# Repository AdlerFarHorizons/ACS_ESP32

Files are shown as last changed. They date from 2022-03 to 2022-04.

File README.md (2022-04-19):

# ACS_ESP32
### Current State of ACS Development (April 2022)

The Altitude Control System has been updated to work with the ESP32 Microcontroller which has enabled wireless file sharing via WiFi. The exact module is the **DOIT ESP32 DEVKIT V1**. 

**Firmware**

The [ACS_ESP32 Code](https://github.com/AdlerFarHorizons/ACS_ESP32) has been organized for clarity, usage, and further development. The code now lives publicly within the [Adler Far Horizons GitHub](https://github.com/AdlerFarHorizons). Additionally, the code and the libraries are packaged by the [PlatformIO](https://platformio.org/platformio-ide) package, which runs within [VS Code](https://code.visualstudio.com/), and should be used to maintain and update the code. Cloning the repository from within GitHub will ensure PlatformIO compiles the code properly. 



The following are updates to the code:



- Code has been organized into separate header files (_name_.h) so as to keep all related code for specific peripherals in separate files. This allows the programmer to quickly find specific functions.
- Wireless file retrieval has been added. The microcontroller will broadcast a hotspot with SSID: “ACS SD-CARD”. The SD Card content can be displayed by entering the IP-ADDRESS: “192.168.4.1” into a web browser after establishing wifi connection. 

To access wifi settings, 

1. Turn on the ACS by using the Toggle ON/OFF switch or by plugging using a USB cable.

2. Using your computer (or mobile device), look for the “ACS SD-Card” Hotspot under the WIFI settings. You do not need a password to access the hotspot.

3. Identify the 3-position switch on the ACS Faceplate. Place this switch to the Closed Position (or the center position), and Press the Button as indicated on the Display. You should now see the IP Address displayed, which should be “192.168.4.1”.

   1. Sometimes the connection is poor, and you may need to bring the ACS closer to you, or you may need to reestablish the WIFI connection by turning off/on your wireless antenna on your computer/mobile device.

4. If your connection is established, you should now see a window as shown below: 

Within this window you may browse through the content within the SD Card by selecting Directory. If you wish to download a file, you can copy/paste the full name of the file and paste it into the Downloads prompt window. 

The use of WIFI is to be able to download the param.txt file, edit it and upload it back into the ACS SD Card. Additionally, one can download the datalog.csv, which contains all the flight ACS data. Ideally, one should not have to remove the SD Card from the board. 

__Note: I’ve noticed that deleting a file via WIFI sends it to the .Trash Folder. It doesn’t fully delete the file. So when the script runs and looks for a file within the list of files, if the file exists within the .Trash folder, then the code will send a True that the file exists. The code either needs a exception to not search within .Trash or a “Permanently Delete” function that deletes the content within .Trash.__

### Design Files, Notes, and Code

[GitHub - ACS_ESP32](https://github.com/AdlerFarHorizons/ACS_ESP32)

[Google Drive: System Redesign Concept 2021/22](https://drive.google.com/drive/folders/1W37AFGbH8UgUThIRDDYVn1NRzvqxMLDn)

- [PCB Design Files](https://drive.google.com/drive/folders/1NPGxpG3kCgMrHuZ5ZHsxEYcvnIpvRIrO?usp=sharing)
- [PCB Schematic PDF](https://drive.google.com/file/d/19PMDI1tQQiT3bByivIbot_-rFZreG9Ll/view?usp=sharing)

[Purchase Materials****](https://docs.google.com/spreadsheets/d/1xs60UxvHJ-fiQykCOm7pP0R7RBD7VAjFjShzD04MD6w/edit#gid=0)

**Compiling using Arduino**

To compile and upload the script file using Arduino, you must install the ESP32 Arduino Boards using instructions found here.

**Instructions**: [Installing ESP32 in Arduino IDE](https://randomnerdtutorials.com/installing-the-esp32-board-in-arduino-ide-windows-instructions/) 

Upon Install, select the **DOIT ESP32 DEVKIT V1 **Board from the drop down menu within **Tools/Board/ESP32 Arduino/. **The this dropdown menu is shown below:



**Printed Circuit Board (PCB)**

The PCB for the ACS has had several modifications. Primarily, the Teensy 3.6 Microcontroller has been exchanged for the WIFI capable microcontroller [**ESP-WROOM-32 ESP-32S Development Board**](https://www.amazon.com/dp/B08D5ZD528?psc=1&ref=ppx_yo2ov_dt_b_product_details)**. **This microcontroller does not include an SD Card Reader, which is why an [SD Card Reader Breakout Board](https://www.sparkfun.com/products/13743) has been added to the new design. 

In addition to the microcontroller modifications, the PCB now utilizes a few surface-mounted devices. 

- **Power**: The previous design used the [LM7805 Voltage Regulator](https://www.sparkfun.com/datasheets/Components/LM7805.pdf) which dropped the 7.2V to 5V using a conventional heat dissipation voltage regulator. This approach worked, but consumed much higher current draw. Therefore, the DC-DC voltage regulator was exchanged for a low-dropout voltage regulator. The selected voltage regulator is now the [MC33269](https://www.onsemi.com/pdf/datasheet/mc33269-d.pdf). 
- **Logic Level Shifter: The original [4-channel I2C-safe Bi-directional Logic Level Converter - BSS138](https://www.adafruit.com/product/757) has been stripped down to only use 1 of the [BSS138](https://www.onsemi.com/pdf/datasheet/bss138-d.pdf) configured to convert signals from low voltage 3V3 to 5.0 Volts.**
- **Actuator**: The current actuator is the L12-50-210-6-R, which runs a servo motor to extend the actuator. However, this actuator does not provide feedback positional data, therefore the recommendation is to upgrade the actuator to the [**L12-50-210-6-I**](https://s3.amazonaws.com/actuonix/Actuonix+L12+Datasheet.pdf)**. **The L12-I version contains an integrated microcontroller which allows the user to obtain positional feedback data. 

**Connection Diagram**

**AA Battery Set for Actuator + Primary Board**

The current AA battery set used in the ACS is the [ Xeno XL-060F AA 2400mAh 3.6V Lithium Thionyl Chloride (LiSOCI2)](https://www.batteryjunction.com/xl-060f-xeno-aa.html) \[[datasheet](https://files.batteryjunction.com/frontend/files/xeno/datasheet/Xeno-XL-060F-Datasheet.pdf)], which is placed in Series to increase the voltage to 7.2. The ACS uses four (4) AA Batteries - 2 sets in Series, and those two sets are merged in parallel to increase the capacity (mAh).

**External Temperature Battery Board**

This board has been prepared to connect to the primary board, but is placed separately from it in order to be close enough to the heating elements for it to monitor temperatures and hold the two 9V batteries to power the heating element.

- **Temperature:** The temperature is monitored using a [DS18B20 Digital Thermometer](https://datasheets.maximintegrated.com/en/ds/DS18B20.pdf).
- **Batteries:** The 9V batteries are held in place by both the structure of the compartment it will reside in and power the heating through two [5331TR (Leaf-Spring Battery Contacts)](https://www.digikey.com/en/products/detail/keystone-electronics/5331TR/8347168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) each. These battery contacts serve a dual purpose as the screws that will go through them are the same ones being used to mount the board securely.
- **Connection: The board is connected to the primary one using a 5 Pin [Screw Terminal Block](https://www.pololu.com/product/2493) affixed to the bottom of the board which will allow wires to be led through a hole beneath it on the way to the main board.**

****

### NEXT TASKS

**Actuator**

- After providing 6.5V to the L-12-I actuator via the DC-Power Supply, **ensure the actuator responds correctly to the ACS_ESP32 Code**. If it does not respond correctly, change the RC_INPUT_SIG Pin to another pin on the ESP32. I’ve identified that some of the pins on the ESP32 seem to short out the microcontroller and/or do not behave as intended. On the code, navigate to actuator.h and find line “**int actuator_pin = 17;”.** Test out a different GPIO pio, upload code, and test for actuator response. 

  - If the actuator ‘jerks’ back and forth when attempting to reach a certain position, the datasheet recommends to “place a 1–4Ω resistor in series with the actuator’s red V+ lead wire”.

- **Actuator Feedback** via the POS_FEEDBACK_SIG pin, which has been connected to GPIO13, must be checked for incoming data. After declaring the POS_FEEDBACK_PIN as an int, use pinMode(POS_FEEDBACK_PIN, INPUT); to initialize the pin on the microcontroller, one should be able to read the voltage using the analogRead() function. One should expect a voltage reading from 0-255, which then can be mapped using map() to correspond to a percentage. 

- Actuator Pins CURR_INPUT_SIG and VOLT_INPUT_SIG have purposefully been disconnected from the microcontroller. These features for controlling the actuator are unnecessary as the actuator will be controlled via the RC_INPUT_SIG.

**The Heating Element**

- The Heating Element needs to be tested the new downsize of voltage output. Originally the heating element uses 3 batteries in series of 9V totalling 27V. Now, the downsize should yield 18V. This downsize has been considered given the usage of an aluminum pipe for heat distribution. 
- Code: Create Algorithm to measure heat transfer between the heating element and the internal electronics, by measuring the temperature outside the heating element (battery board) and the internal Pressure Sensor thermometer. Using these temperatures, create a function that activates the heating element below a specific temperature, and conversely deactivates the heating element when temperatures reach a specific maximum. 
- Heating Element Transistor 2N2222 schematic needs to be tested prior to finalizing the schematic design of the primary board. 



Above: Circuit concept idea for the resistor being the heating element connected to one end of the transistor 2N2222.



Above: Schematic capture of the heating element connector. Here the heating element is connected to one side of the NPN transistor. The Base is connected to the microController, and the Collector is connected to the negative end of the 9V battery set, which is connected in series. 

**Code**

Within the void setup() function, ensure that when the sd_setup() does not create a new file each time the boot process occurs. The ACS should conserve and append the currently existing logfile if it exists. If the file does not exist, the code is instructed to write the parameters below:

else
{ unsigned long size = logFile.size();
  Serial.print("Filesize: "); Serial.println(size);
  delay(5000);
  if (size < 500){
    display.clearDisplay();
    display.println("Creating new File");
    display.display();
    delay(5000);

    String log = 
                "Far Horizons | Adler Planetarium" + String("\n") + 
                "Flight Number: " + "," +            String(flightNum) + "\n" + 
                "Firmware: " + "," +                  String(the_sketchname) + "\n" + 
                "Compiled on: " +  "," +               String(__DATE__) +  " at " +  String(__TIME__) + "\n" +
                "Venting Altitude (m): " + "," +      String(VENT_ALT) + "\n" + 
                "Float Time (min): " + "," +          String(FLOAT_TIME) + "\n" + 
                "Max Float Altitude (m): " + "," +   String(MAXFLOATALT) + "\n" + 
                "Release Position %: " + "," +        String(RELEASE_POS) + "\n" + 
                "Venting Position %: " + "," +        String(OPEN_POS) + "," + 
                "Closed Position" + "," + String(CLOSED_POS) + "\n";

Currently this section of the code does not work as intended. Instead, the code creates a new file and does not append the parameters found above.

**ACS Primary PCB**

- Label Pins on Connectors using layer tNames and bNames.
- Ensure Connector are placed in the correct location to help diminish excess wire routing and unnecessary wire-curvatures.
- Rework routes after device placement and use ratsnest to create the correct ground plane

**Currently Wired Diagram on Breadboard: **

  

**Full Schematic Diagram with External Temp Board**

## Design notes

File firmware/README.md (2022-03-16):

# ACS_ESP32

This code runs on PlatformIO using VSCode.
Use Microcontroller: esp32doit-devkit-v1

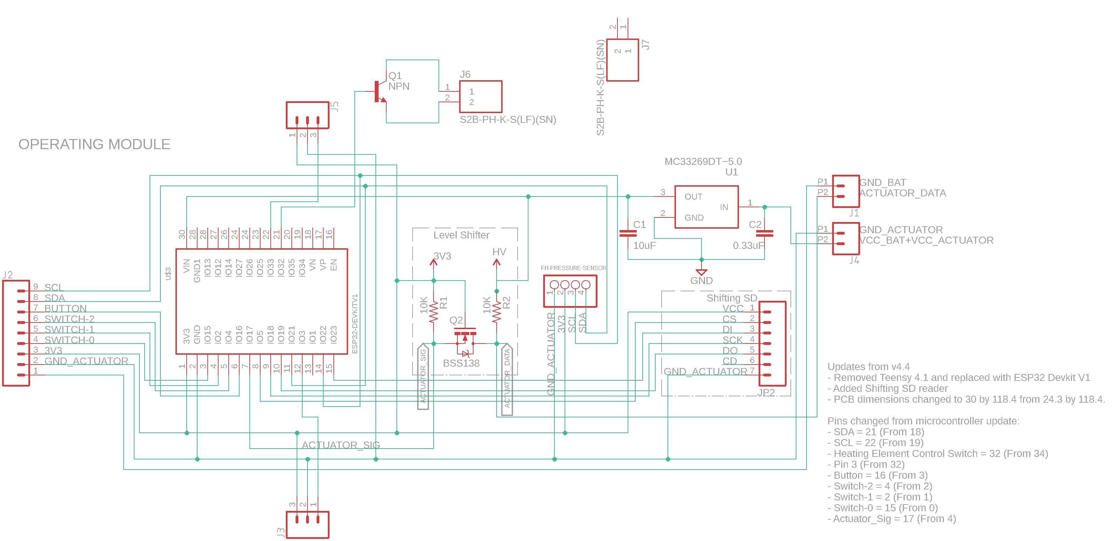
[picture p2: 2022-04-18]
pcb/ACS_5.X_REDESIGN/5.1.1/ACS_Schematic.png

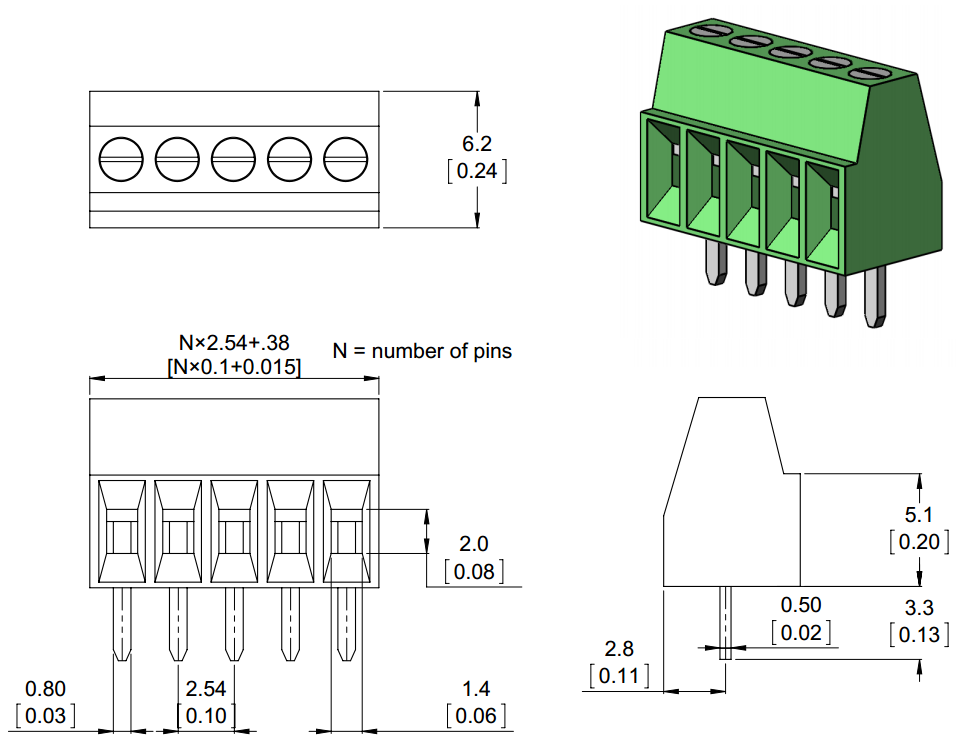
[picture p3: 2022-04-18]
pcb/datasheet/block_connectors.png

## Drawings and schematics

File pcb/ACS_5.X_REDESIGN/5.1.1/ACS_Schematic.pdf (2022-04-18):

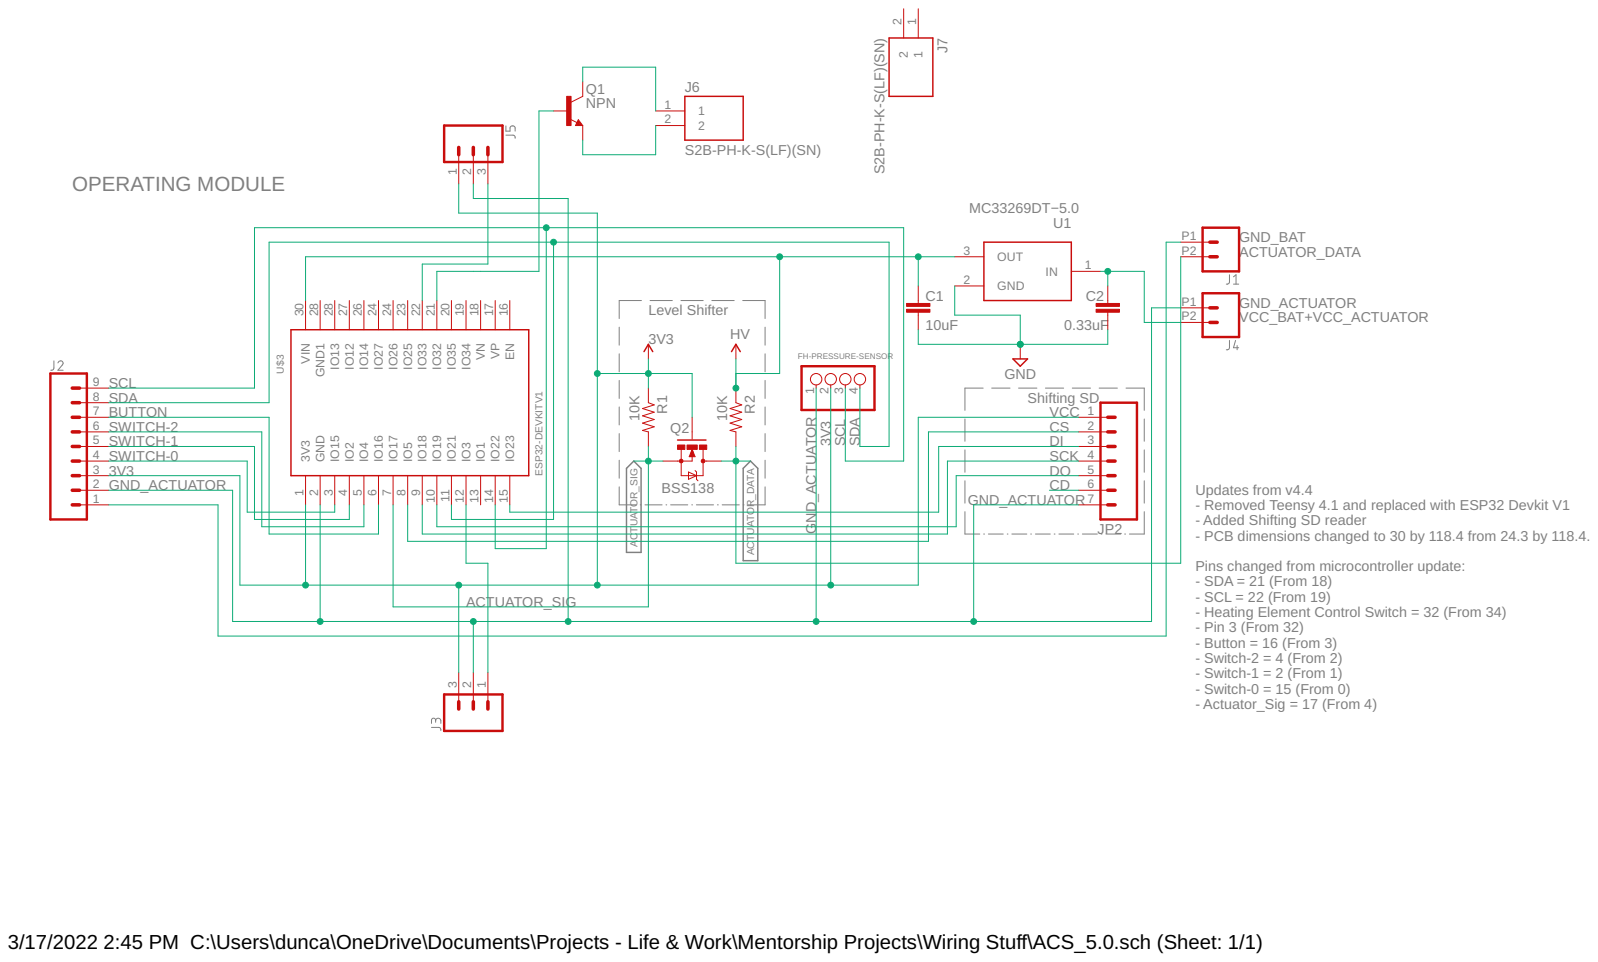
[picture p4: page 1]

CS 2
DI 3
SCK 4
DO 5

Updates from v4.4
- Removed Teensy 4.1 and replaced with ESP32 Devkit V1
- Added Shifting SD reader
- PCB dimensions changed to 30 by 118.4 from 24.3 by 118.4. Pins changed from microcontroller update: - SDA = 21 (From 18)

- SCL = 22 (From 19)
- Heating Element Control Switch = 32 (From 34)
- Pin 3 (From 32)
- Button = 16 (From 3)
- Switch-2 = 4 (From 2)
- Switch-1 = 2 (From 1)
- Switch-0 = 15 (From 0)
- Actuator_Sig = 17 (From 4)

3/17/2022 2:45 PM C:\Users\dunca\OneDrive\Documents\Projects - Life & Work\Mentorship Projects\Wiring Stuff\ACS_5.0.sch (Sheet: 1/1)

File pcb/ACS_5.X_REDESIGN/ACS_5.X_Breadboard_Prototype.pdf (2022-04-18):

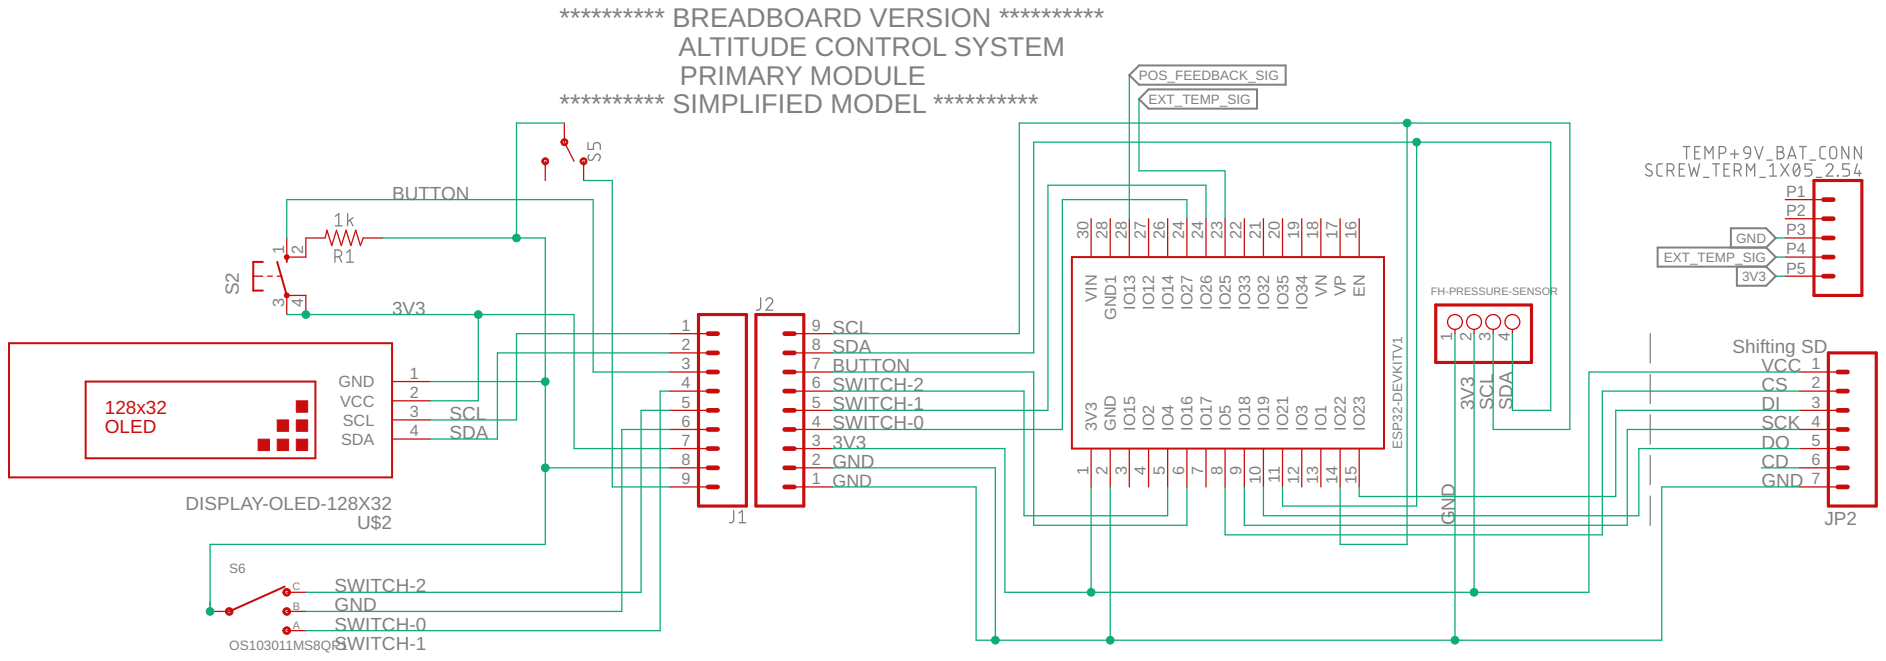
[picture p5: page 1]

********** BREADBOARD VERSION ********** ALTITUDE CONTROL SYSTEM

SCK 4
DO 5
6 CD

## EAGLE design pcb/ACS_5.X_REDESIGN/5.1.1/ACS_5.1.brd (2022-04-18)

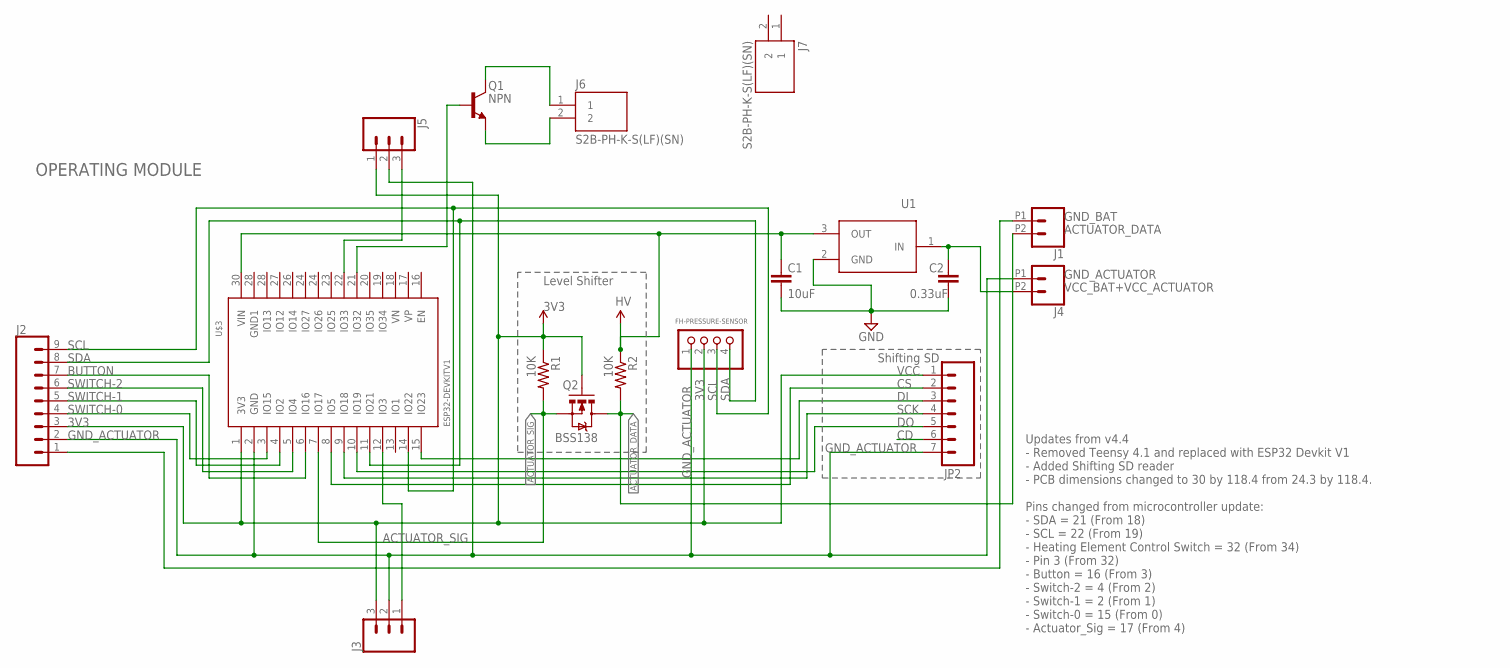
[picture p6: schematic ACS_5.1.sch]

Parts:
C1: 10uF; CAPC1608X85
C2: 0.33uF; CAPC1608X85
FH-PRESSURE-SENSOR: PINHD-1X4; 1X04
J1, J4: CONN_022.54MM_SCREWTERM; 1X02_2.54_SCREWTERM
J2: CONN_09; 1X09
J3, J5: CONN_03; 1X03
J6, J7: S2B-PH-K-S(LF)(SN); JST_S2B-PH-K-S(LF)(SN)
JP2: M07; 1X07
Q1: NPN; SOT95P237X112-3N
Q2: BSS138; SOT23-3
R1, R2: 10K; 0603-RES
U1: MC78M05BDTRKG
U$3: ESP32DEVKITV1; ESP32-DEVKITV1

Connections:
3V3: FH-PRESSURE-SENSOR.2, J2.3, J3.3, J5.1, JP2.1, Q2.1 (G), R1.1, U$3.1 (3V3)
ACTUATOR_DATA: J1.P2 (2), Q2.3 (D), R2.2
ACTUATOR_SIG: Q2.2 (S), R1.2, U$3.7 (IO17)
BUTTON: J2.7, U$3.6 (IO16)
GND: C1.2, C2.2, U1.2 (GND)
GND_ACTUATOR: FH-PRESSURE-SENSOR.1, J2.2, J3.2, J4.P1 (1), J5.2, JP2.7, U$3.2 (GND)
GND_BAT: J1.P1 (1), J2.1
HV: C1.1, R2.1, U1.3 (OUT), U$3.30 (VIN)
unnamed: J5.3, U$3.22 (IO33)
unnamed: J6.1, Q1.3 (C)
unnamed: J6.2, Q1.1 (E)
unnamed: Q1.2 (B), U$3.21 (IO32)
unnamed: J3.1, U$3.12 (IO3)
unnamed: JP2.3, U$3.15 (IO23)
unnamed: JP2.2, U$3.8 (IO5)
unnamed: JP2.4, U$3.9 (IO18)
unnamed: JP2.5, U$3.10 (IO19)
SCL: FH-PRESSURE-SENSOR.3, J2.9, U$3.14 (IO22)
SDA: FH-PRESSURE-SENSOR.4, J2.8, U$3.11 (IO21)
SWITCH-0: J2.4, U$3.3 (IO15)
SWITCH-1: J2.5, U$3.4 (IO2)
SWITCH-2: J2.6, U$3.5 (IO4)
VCC_BAT+VCC_ACTUATOR: C2.1, J4.P2 (2), U1.1 (IN)

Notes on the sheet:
OPERATING MODULE
Level Shifter
Updates from v4.4 - Removed Teensy 4.1 and replaced with ESP32 Devkit V1 - Added Shifting SD reader - PCB dimensions changed to 30 by 118.4 from 24.3 by 118.4. Pins changed from microcontroller update: - SDA = 21 (From 18) - SCL = 22 (From 19) - Heating Element Control Switch = 32 (From 34) - Pin 3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
SCK
VCC
Shifting SD

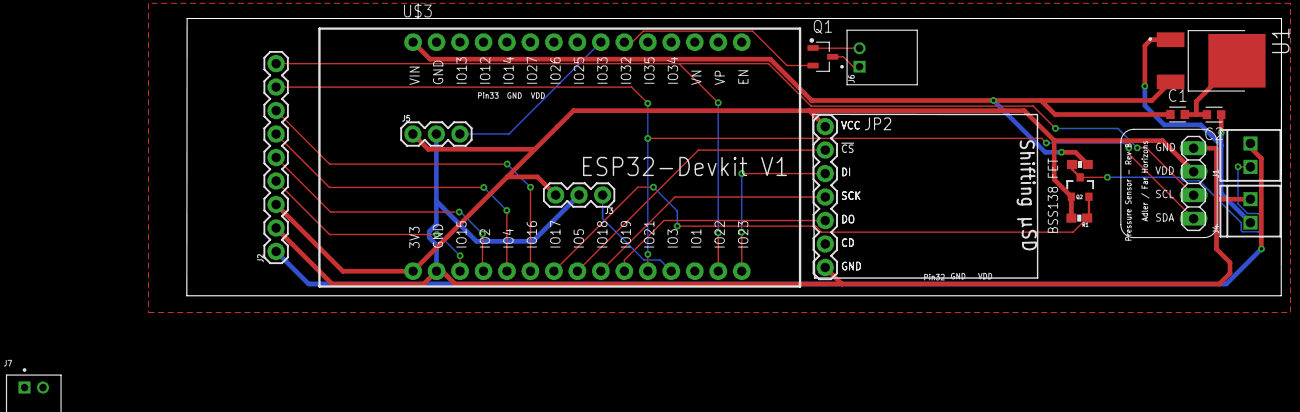
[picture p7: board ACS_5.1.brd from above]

Board: 2 copper layers, 118.4 x 30.0 mm, 17 parts (0 on the bottom side), 23 nets.

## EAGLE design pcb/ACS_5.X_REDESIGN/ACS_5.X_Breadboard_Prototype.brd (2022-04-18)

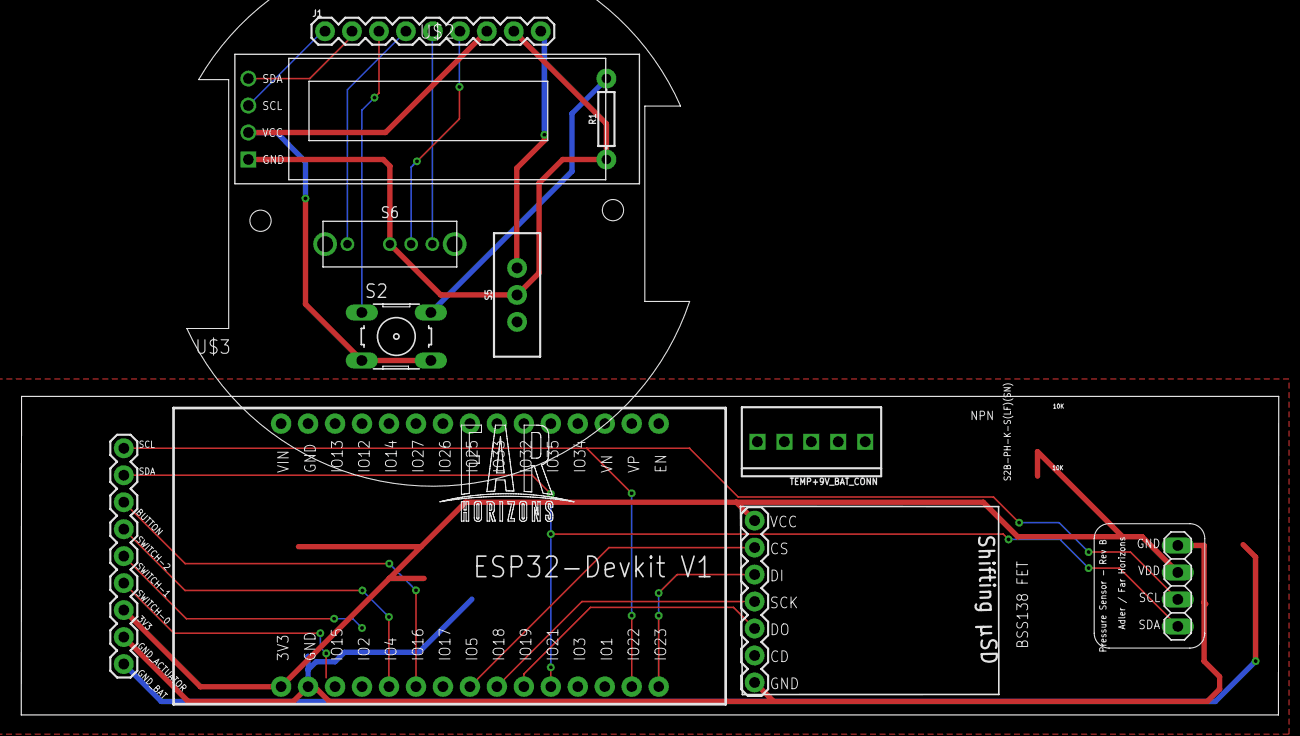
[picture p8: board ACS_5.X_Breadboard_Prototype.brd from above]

Board: 2 copper layers, 118.4 x 30.0 mm, 11 parts (0 on the bottom side), 15 nets.

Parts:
FH-PRESSURE-SENSOR: 1X04
J1, J2: 1X09
JP2: 1X07
R1: 1k; AXIAL-0.3
S2: B3F-10XX
S5: SWITCH_SPDT_PTH_11.6X4.0MM
S6: OS103011MS8QP1; OS102011MS8QP1
TEMP+9V_BAT_CONN: SCREW_TERM_1X05_2.54; 1X05_2.54_SCREWTERM
U$2: DISPLAY-OLED-128X32
U$3: ESP32DEVKITV1; ESP32-DEVKITV1

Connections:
3V3: FH-PRESSURE-SENSOR.2, J1.7, J2.3, JP2.1, S2.3, S2.4, TEMP+9V_BAT_CONN.P5, U$2.2, U$3.1
BUTTON: J1.3, J2.7, S2.1, U$3.6
EXT_TEMP_SIG: TEMP+9V_BAT_CONN.P4, U$3.23
GND: FH-PRESSURE-SENSOR.1, J1.8, J2.1, J2.2, JP2.7, R1.P$1, S5.2, S6.2, TEMP+9V_BAT_CONN.P3, U$2.1, U$3.2
unnamed: R1.P$2, S2.2
unnamed: J1.9, S5.1
unnamed: JP2.3, U$3.15
unnamed: JP2.2, U$3.8
unnamed: JP2.4, U$3.9
unnamed: JP2.5, U$3.10
SCL: FH-PRESSURE-SENSOR.3, J1.1, J2.9, U$2.3, U$3.14
SDA: FH-PRESSURE-SENSOR.4, J1.2, J2.8, U$2.4, U$3.11
SWITCH-0: J1.6, J2.4, S6.3, U$3.24
SWITCH-1: J1.5, J2.5, S6.4, U$3.24
SWITCH-2: J1.4, J2.6, S6.1, U$3.5

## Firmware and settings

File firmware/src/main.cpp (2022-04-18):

/*
Altitudde Control System 
Adler Planetarium | Far Horizons

By: Jesus Garcia
ACS WIFI on ESP32

4/11/2022
- Password removed.
- Updated WebPage Style

 3/26/2022
WIFI is enabled at startup and can be assessed via Switch State: Closed and Button Press
SSID has been added: ACS SD-CARD PSWORD: xxxxxxx
?? Do we need a Password? 
When Switch State is in Closed Possition, button may be pressed to enter WIFI.

External TEMP has been added and called within setup and loop.
TODO: Add Temperature Control for Heating Element

So far, this code compiles with Pressure code, Actuator, SD + Wifi, reads/writes parameter file. 
     reads all variables from sensors, calculates dA/dt, and writes into var = dataString 
     and appends to SD Card

*/

#include <Arduino.h>
#include <math.h>             // math .. Pressure Sensor needs this
#include <String.h>
#include <Wire.h>             //I2C library fort OLED and Pressure Sensor
#include <SPI.h>              //SPI library for SD card
#include <SD.h>               //SD    ********MUST BE VERSION 1.2.2 TO WORK WITH TEENSY********
#include <EEPROM.h>


// Local Files
#include "actuator.h"
#include "Globals+switch.h"
#include "pressure.h"
#include "sd+wifi.h"
#include "oled.h"
#include "param.h"
#include "SoftwareFunctions.h"
#include "temp.h"

String the_sketchname, version;
String header;


// displays at startup the Sketch running in the Arduino
void display_Running_Sketch (void){
  String the_path = __FILE__;
  int slash_loc = the_path.lastIndexOf('/');
  String the_cpp_name = the_path.substring(slash_loc+1);
  int dot_loc = the_cpp_name.lastIndexOf('.');
  the_sketchname = the_cpp_name.substring(0, dot_loc);
  version = the_sketchname.substring(0,4);
  
  Serial.println("\nArduino is running Sketch: ");
  Serial.println(the_sketchname);
  Serial.println("Compiled on: ");
  Serial.println(__DATE__);
  Serial.println(" at ");
  Serial.println(__TIME__);
  Serial.println("\n");
}

void setup() {
  Serial.begin(115200);

  display_Running_Sketch();

  // Setup Pins
  pinMode(switch0, INPUT_PULLUP);
  pinMode(switch1, INPUT_PULLUP);
  pinMode(switch2, INPUT_PULLUP);
  
  // initialize Pin for the button
  pinMode(buttonPin, INPUT_PULLUP);
  buttonPressed=FALSE;

    // Attach Actuator
  actuator.attach(actuator_pin);

    // Setup Pressure Sensor
  pressure_setup();
  
  // EXT Temp Sensor Setup
  temp_setup();

  // Setup Display
  oled_setup();

  // Setup SD
  sd_setup();

  //Access Point Initialized
  Start_Wifi();

  // Read Parameters File and/or creates param.txt file (with default values) if not present
  readparam(SD);

  // get the current altitude for deciding how to initialize
  currentAltitude=getMedianPressure(&currentTemp);
  
  
  // if the switch is indicating that we are in flight mode (that is we were in the middle of a 
  // mission when the power cycled) them attempt to pick up from where we left
    FS fs(SD);
    File logFile;

  if (switchPos(currentAltitude)==FLIGHT) {
    char lineBuf[250];          //For log file


    // open logfile -> dataFile
    if ((logFile = fs.open(dataFile, FILE_READ))) { 
        Serial.println("Reading LAST LINES on File .......");
      // read the last line of the log file to get programState, the timeOffset, 
      // actuator extension, and the start of floating
      while (logFile.available()) {
          logFile.readBytesUntil('\n',lineBuf,150);    
      }

      Serial.println("\n***************************** \n");
      Serial.print("Last Line in Buffer: ");
      Serial.println(lineBuf);
      // we should have the last line now
      sscanf(lineBuf, "%ld %*d %d %f %ld",&timeOffset, &programState, &currentActuatorExtension, &floatStartTime);
      Serial.print("Time Offset: "); Serial.println(timeOffset);
      Serial.print("Program State: "); Serial.println(programState);
      Serial.print("Current Actuator Extension: "); Serial.println(currentActuatorExtension);
      Serial.print("Float Start TIme: "); Serial.println(floatStartTime);
      Serial.println("\n***************************** \n");
    
      SetStrokePerc(currentActuatorExtension);
    }
  }
  
////////////////////////////

//   TODO   FIX this section... Check if file exists and report if file exits, otherwise create file and append log parameters.

  // open logfile
  if (!(logFile = fs.open(dataFile, FILE_APPEND))) { 
    Serial.println("Failed to open logfile.");
    display.clearDisplay();
    display.setTextSize(2); 
    display.setTextColor(WHITE);
    display.setCursor(18, 0);
    display.println("LOGFILE");
    display.setCursor(18, 16);
    display.println("FAILED");
    display.display();
    delay(5000);
    //return;
    }
  else
    { unsigned long size = logFile.size();
      Serial.print("Filesize: "); Serial.println(size);
      delay(5000);
      if (size < 500){
        display.clearDisplay();
        display.println("Creating new File");
        display.display();
        delay(5000);

        String log = 
                    "Far Horizons | Adler Planetarium" + String("\n") + 
                    "Flight Number: " + "," +            String(flightNum) + "\n" + 
                    "Firmware: " + "," +                  String(the_sketchname) + "\n" + 
                    "Compiled on: " +  "," +               String(__DATE__) +  " at " +  String(__TIME__) + "\n" +
                    "Venting Altitude (m): " + "," +      String(VENT_ALT) + "\n" + 
                    "Float Time (min): " + "," +          String(FLOAT_TIME) + "\n" + 
                    "Max Float Altitude (m): " + "," +   String(MAXFLOATALT) + "\n" + 
                    "Release Position %: " + "," +        String(RELEASE_POS) + "\n" + 
                    "Venting Position %: " + "," +        String(OPEN_POS) + "," + 
                    "Closed Position" + "," + String(CLOSED_POS) + "\n";
        // writeFile(SD, dataFile, log);
        appendFile(SD, dataFile, log);
        header = "Current Time,Switch State,Program State,Actuator Extension,Float Start Time,Pressure,Altitude,dAdt,Temp,ExtTemp\n";
        appendFile(SD, dataFile, header);
        
        Serial.println("LOG FILE CREATED with DEFAULT PARAMETERS");
        delay(500);
      }
    }

////////////////////////////
  String parameterText = "Venting Alt: " + String(VENT_ALT) + " m" + "\n" + 
                         "Float Time: "  + String(FLOAT_TIME) + " min" + "\n" + 
                         "MaxFloatAlt: " + String(MAXFLOATALT) + " m" + "\n" + 
                         "Open/Closed_pos: " + String(OPEN_POS) + "/" + String(CLOSED_POS) + " %";
                         
  OLEDScrollText(parameterText);    // prints parameters on OLED with scrolling text
  delay(2000);
  
  lastLogTime=-9999;
  Serial.println(header);
}

void loop(){
  int switchState;
  long int currentTime;
  float currentPressure,currentTemp,currentAltitude,currentDAdt;
  // get time
  currentTime=millis()+timeOffset;
  
  // get EXT Temp
  get_temp();

  // get pressure sensor values
  currentPressure= getMedianPressure(&currentTemp);

  // derive altitude and derivative  
  currentAltitude=altitudeFromPressure(currentPressure);
  currentDAdt=dAdt_fiT_2(currentAltitude,currentTime);

  // process switch and button
  switchState = switchPos(currentAltitude);
  if (digitalRead(buttonPin) == HIGH) buttonPressed=TRUE; 
  
  // Prepares all variable data for write to SD.
  dataString = 
    String(currentTime) + "," + 
    String(switchState) + "," + 
    String(programState) + "," + 
    String(currentActuatorExtension) + "," + 
    String(floatStartTime) + "," + 
    String(currentPressure) + "," + 
    String(currentAltitude) + "," + 
    String(currentDAdt) + "," + 
    String(currentTemp) + "," + 
    String(ext_temp) + "\n"; // Replace with external Temp sensor Dallas...
    lastLogTime=currentTime;
  
  // Append to SD.
  appendFile(SD, dataFile, dataString);     //Append the contents of the dataString to the end of the file on a new line.

  display.clearDisplay();
  display.setCursor(0,20);
  logFileStatus();        // CHECK STATUS OF SD CARD

  switch (switchState) {
    case(RELEASE):
        display.setCursor(0,0);
        display.println("Press to RELEASE");
        display.setCursor(0,16);
        display.println("Actuator will retreat");

        if (buttonPressed) {
          display.clearDisplay();
          display.setCursor(16,16);
          display.println("Button pressed");
          delay(100);
          buttonPressed=FALSE;
          SetStrokePerc(RELEASE_POS);
        }
        programState=GROUND;
        logFileStatus();        // CHECK STATUS OF SD CARD
        display.display();
        break;
    case(CLOSED):
        display.setCursor(0,0);
        display.println("CLOSED POSITION");
        display.print("Pres: "); display.println(currentPressure);
        display.println("Closing Nozzle...");
        display.println("PRESS BUTTON FOR WIFI");
        logFileStatus();        // CHECK STATUS OF SD CARD

        if (buttonPressed) {
          display.clearDisplay();
          display.setCursor(0,0); display.println("WIFI READY ");
          
          // Print IP Address on Network
          Serial.print("WIFI SSID: "); Serial.println(ssid);
          display.print("SSID: "); display.println(ssid);  
          display.println();
          Serial.print("IP address: ");  display.print("IP: ");
          Serial.println(IP);               display.println(IP);
          display.display();
          
          while(switchPos(currentAltitude) == 2){
            server.handleClient(); 
            switchState = switchPos(currentAltitude);
          }
          buttonPressed=FALSE;
        }
        display.display();
        SetStrokePerc(CLOSED_POS);
        programState=GROUND;
        break;
    case(FLIGHT):
        switch (programState) {
          case (GROUND):
              programStateString = "GROUND";
              SetStrokePerc(CLOSED_POS);            // this may take a lot of energy if the actuator can't quite get there
              if (currentAltitude>2000) programState=ASCENT;
              if (!buttonPressed) {
                display.setCursor(0,24); display.setTextColor(BLACK, WHITE); display.print("Press to Start"); display.setTextColor(WHITE, BLACK);
              }
              if (buttonPressed) {
                 display.setCursor(0,24); display.println("... pressed");
                 delay(100);
                 buttonPressed=FALSE;
                 programState=ASCENT;
              }
              break;
          case (ASCENT):
              programStateString = "ASCENT";
              if (currentAltitude>VENT_ALT) {     // this is in meters
                SetStrokePerc(OPEN_POS);
                programState=VENTING;
                N_DAdt_lt_0=0;                
              }
              break;
          case (VENTING):
              programStateString = "VENTING";
              if (currentDAdt<0) {
                N_DAdt_lt_0++;
                if (N_DAdt_lt_0>N_ASCENTRATEBELOWZERO) {
                  SetStrokePerc(CLOSED_POS);
                  programState=FLOATING; 
                  floatStartTime=currentTime;  
                }                            
              }
              break;
          case (FLOATING):
              programStateString = "FLOATING";
              if ((currentTime-floatStartTime>FLOAT_TIME*60*1000) || (currentAltitude>MAXFLOATALT)) {
                SetStrokePerc(RELEASE_POS);
                programState=DESCENT;                               
              }
              break;
          case (DESCENT):
              programStateString = "DESCENT";
              break;
          default:
            programStateString = "Error";
            break;                  
        }
        display.setCursor(0,0); display.print("FLIGHT-"); display.print(programState); display.print(":"); display.print(programStateString); 
        display.setCursor(90,24); display.println(SDStatus);
        if (SDStatus == "SD-ERR"){
          display.setCursor(90,24); 
          display.setTextColor(BLACK, WHITE); display.println(SDStatus); display.setTextColor(WHITE, BLACK);
        }
        display.setCursor(0,8); display.print("Press"); display.setCursor(52,8); display.println("Alt"); display.setCursor(90,8); display.println("Vel");
        display.print(currentPressure,2); display.setCursor(52,16); display.print(currentAltitude,0); display.setCursor(90,16); display.println(currentDAdt);
        display.display();
        break;
  }
  delay(200);
  buttonPressed=FALSE;
}

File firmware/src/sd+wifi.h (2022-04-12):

/*
 * Connect the SD card to the following pins:
 *
 * SD Card | ESP32
 *    D2       -
 *    D3       SS
 *    CMD      MOSI
 *    VSS      GND
 *    VDD      3.3V
 *    CLK      SCK
 *    VSS      GND
 *    D0       MISO
 *    D1       -
 */


///////////////////////////////////////////////////////////////////////////////////////////
//LIBRARIES////////////////////////////////////////////////////////////////////////////////
///////////////////////////////////////////////////////////////////////////////////////////

//General Libraries
#include "FS.h"
#include "SD.h"
#include "SPI.h"

//Wifi Libraries
#include <WiFi.h>              // Built-in
#include <WiFiMulti.h>         // Built-in
#include <ESP32WebServer.h>    // https://github.com/Pedroalbuquerque/ESP32WebServer download and place in your Libraries folder
#include <ESPmDNS.h>



// Set web server port number to 80
ESP32WebServer server(80);
IPAddress IP;

///////////////////////////////////////////////////////////////////////////////////////////
//VARIABLES////////////////////////////////////////////////////////////////////////////////
///////////////////////////////////////////////////////////////////////////////////////////
// File Name Definition
const char * dataFile = "/datalog1.csv";

// //Prepare the data string.
String dataString =""; // holds the data to be written to the SD card
bool sdStatus;
String SDStatus;

//Prepare the pin for the switch.
char WifiPin = 2;
boolean WifiMode = LOW;
boolean WifiSetup = 0;

#define ServerVersion "1.0"
String webpage = "";
bool   SD_present = false;
#define SD_CS_pin           5   //Set the CS pin for the SD card.

#define   servername "fileserver"  // Set your server's logical name here e.g. if 'myserver' then address is http://myserver.local/

//Prepare your wifi connection.
const char* ssid     = "ACS SD-CARD";


///////////////////////////////////////////////////////////////////////////////////////////
//WEBPAGE FUNCTION/////////////////////////////////////////////////////////////////////////
///////////////////////////////////////////////////////////////////////////////////////////
void HomePage();
void File_Download();
void SD_file_download(String filename);
void File_Upload();
void handleFileUpload();
void SendHTML_Header();
void SD_dir();
void printDirectory(const char * dirname, uint8_t levels);
void File_Stream();
void SD_file_stream(String filename);
void File_Delete();
void SD_file_delete(String filename);
void SendHTML_Content();
void SendHTML_Stop();
void SelectInput(String heading1, String command, String arg_calling_name);
void ReportSDNotPresent();
void ReportFileNotPresent(String target);
void ReportCouldNotCreateFile(String target);
String file_size(int bytes);
void Start_Wifi();
void append_page_header();
void append_page_footer();
void Prepare_Data();
void writeFile(fs::FS &fs, const char * path, String message);
void appendFile(fs::FS &fs, const char * path, String message);


void HomePage(){
  SendHTML_Header();
  webpage += F("<a href='/download'><button>Download</button></a>");
  webpage += F("<a href='/upload'><button>Upload</button></a>");
  webpage += F("<a href='/stream'><button>Stream</button></a>");
  webpage += F("<a href='/delete'><button>Delete</button></a>");
  webpage += F("<a href='/dir'><button>Directory</button></a>");
  append_page_footer();
  SendHTML_Content();
  SendHTML_Stop(); // Stop is needed because no content length was sent
}
//~~~~~~~~~~~~~~~~~~~~~~~~~~~~~~~~~~~~~~~~~~~~~~~~~~~~~~~~~~~~~~~~~~~~~~~~~~~
void File_Download(){ // This gets called twice, the first pass selects the input, the second pass then processes the command line arguments
  if (server.args() > 0 ) { // Arguments were received
    if (server.hasArg("download")) SD_file_download(server.arg(0));
  }
  else SelectInput("Enter filename to download","download","download");
}
//~~~~~~~~~~~~~~~~~~~~~~~~~~~~~~~~~~~~~~~~~~~~~~~~~~~~~~~~~~~~~~~~~~~~~~~~~~~
void SD_file_download(String filename){
  if (SD_present) { 
    File download = SD.open("/"+filename);
    if (download) {
      server.sendHeader("Content-Type", "text/text");
      server.sendHeader("Content-Disposition", "attachment; filename="+filename);
      server.sendHeader("Connection", "close");
      server.streamFile(download, "application/octet-stream");
      download.close();
    } else ReportFileNotPresent("download"); 
  } else ReportSDNotPresent();
}
//~~~~~~~~~~~~~~~~~~~~~~~~~~~~~~~~~~~~~~~~~~~~~~~~~~~~~~~~~~~~~~~~~~~~~~~~~~~
void File_Upload(){
  Serial.println("File upload stage-1");
  append_page_header();
  webpage += F("<h3>Select File to Upload</h3>"); 
  webpage += F("<FORM action='/fupload' method='post' enctype='multipart/form-data'>");
  webpage += F("<input class='buttons' style='width:40%' type='file' name='fupload' id = 'fupload' value=''><br>");
  webpage += F("<br><button class='buttons' style='width:10%' type='submit'>Upload File</button><br>");
  webpage += F("<a href='/'>[Back]</a><br><br>");
  append_page_footer();
  Serial.println("File upload stage-2");
  server.send(200, "text/html",webpage);
}
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

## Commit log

2022-04-14 Update Pin no. for ESP32
2022-04-18 adding pcb
    [ACS_5.1.brd, ACS_5.1.sch, ACS_5.3.brd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]

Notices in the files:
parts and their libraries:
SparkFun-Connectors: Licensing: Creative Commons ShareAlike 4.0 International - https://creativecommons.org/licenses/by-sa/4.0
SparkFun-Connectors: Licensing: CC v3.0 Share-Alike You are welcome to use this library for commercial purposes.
